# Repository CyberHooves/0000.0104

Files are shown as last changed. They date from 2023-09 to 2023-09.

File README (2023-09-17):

HAOS REDRO PN: 0000.0104
========================

This is a 1.2kW SMPS for audio amplifiers designed to fit within a 1U case.

Input: 400V DC
Output 1: +100V, 6A
Output 2: -100V, 6A
Output 3: +15V, 500mA
Output 4: -15V, 500mA
Output 5: +12V, 1A
Output 6: +12V, 500mA, referenced to Output 2.

The main outputs are unregulated and it is reccomended to use a suitable power factor correction circuit in applications where line regulation is necessary.
Auxiliary outputs 3 and 4 are provided for small-signal curcuits. Output 6 is provided for class-D amplifiers that require a gate drive supply referenced to the negative supply rail. 
Isolated and non-isolated inputs are provided to shut down the converter on J10 and J11, respectively. Oveheating protection is provided by a thermostat mounted on the heatsink.

This repository is released under CERN-OHL-S 2.0

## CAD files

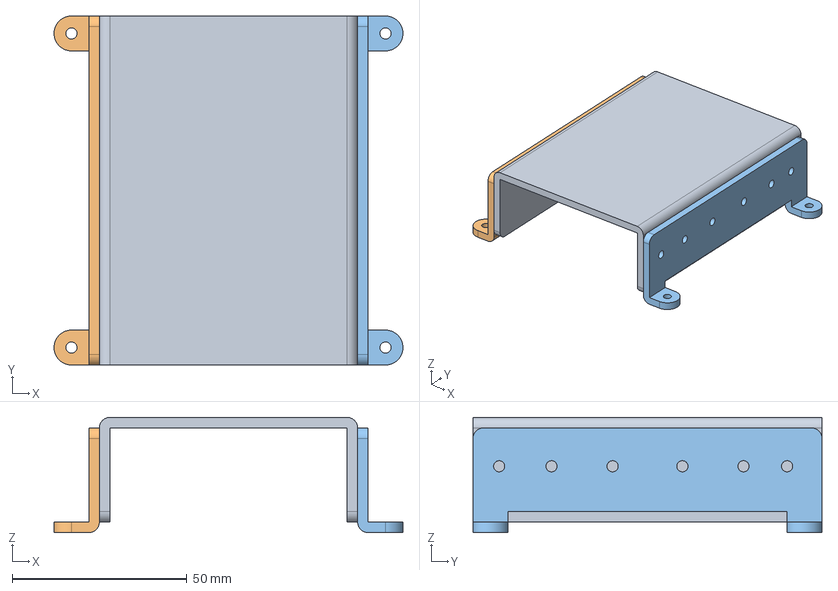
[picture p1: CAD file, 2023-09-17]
Heatsink.FCStd
100.0 x 100.0 x 33.0 mm
Top section
Primary side bracket
Secondary side bracket

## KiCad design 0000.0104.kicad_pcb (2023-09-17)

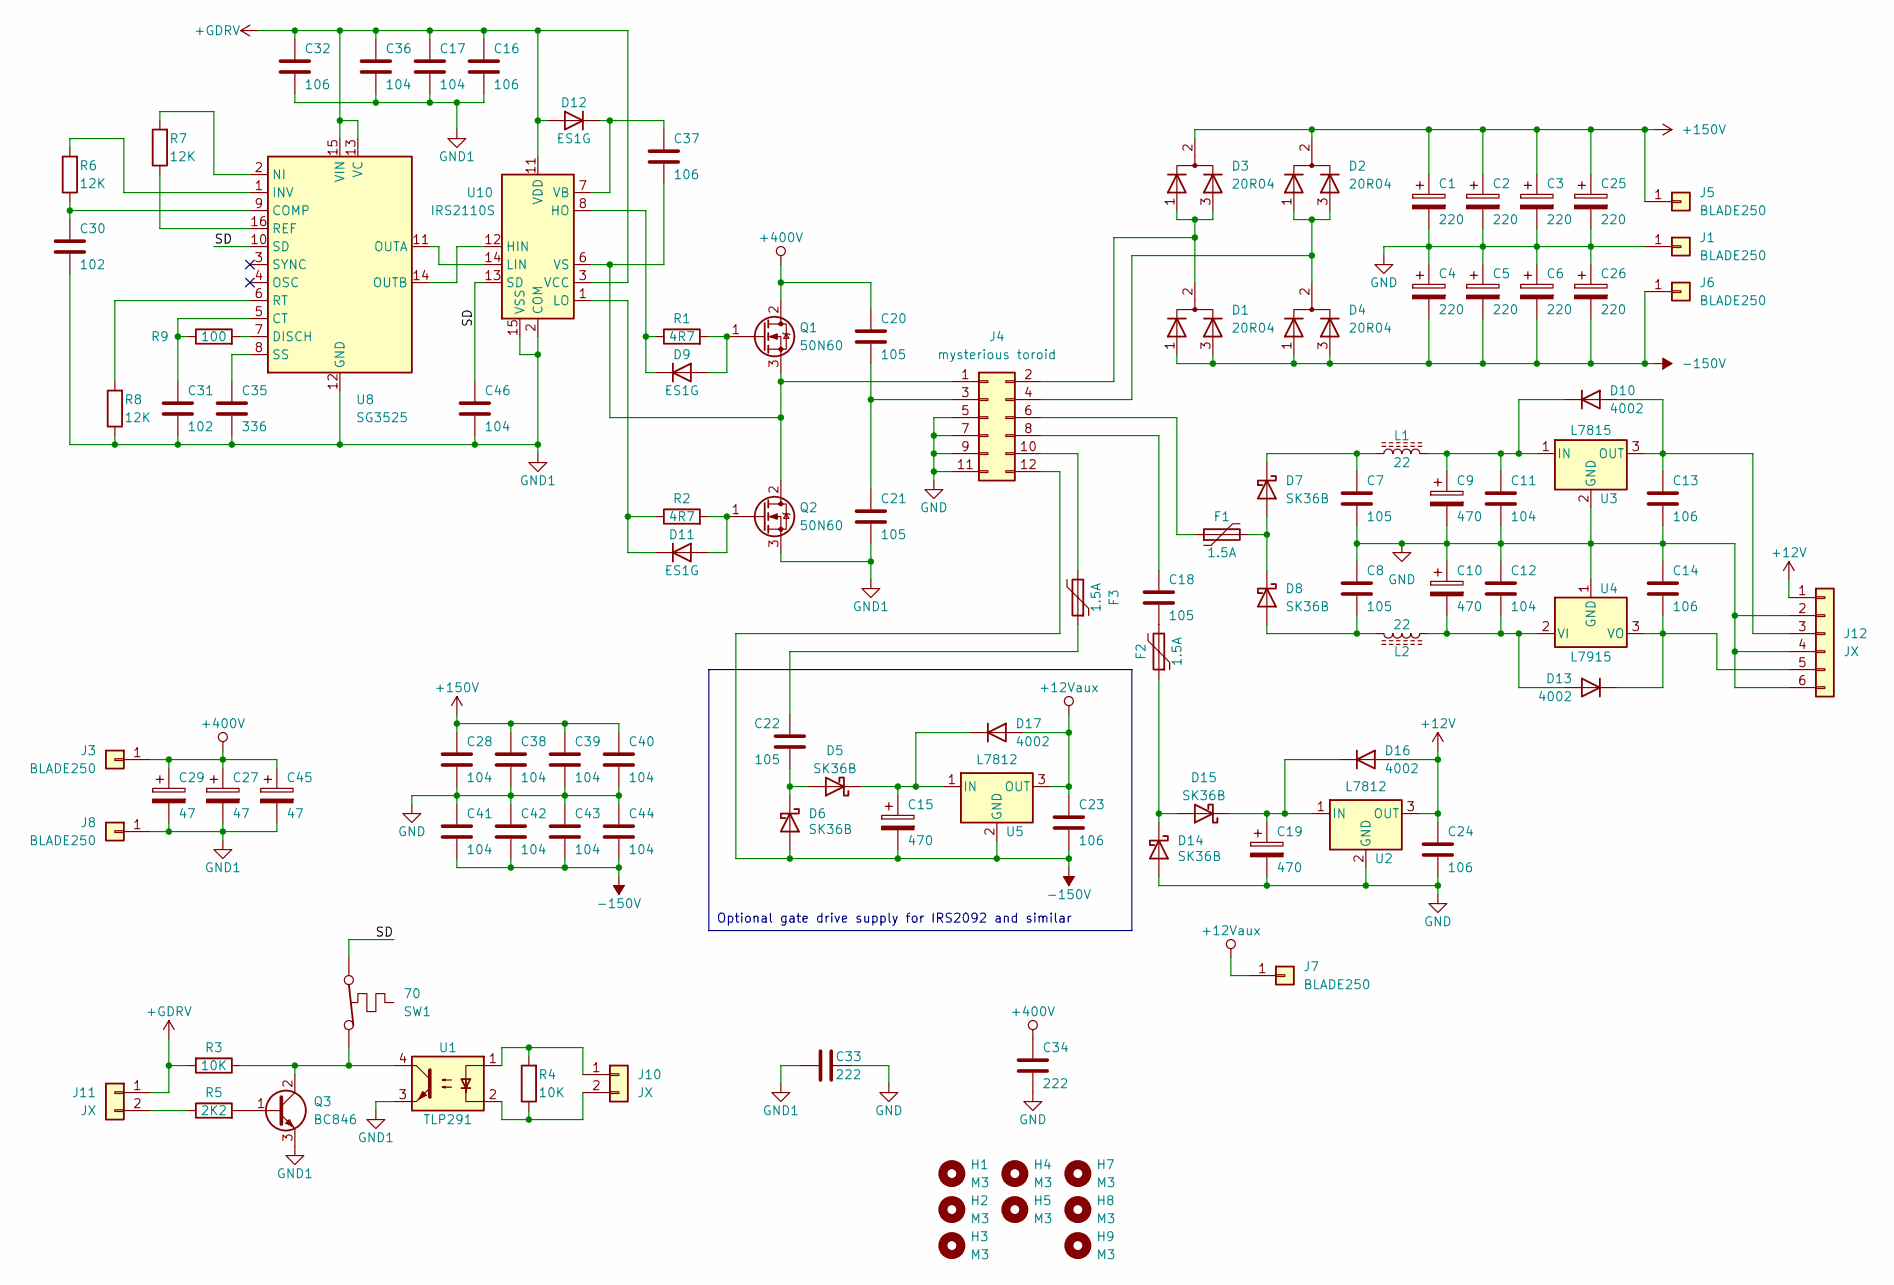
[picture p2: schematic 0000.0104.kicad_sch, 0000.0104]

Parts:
C1, C2, C3, C4, C5, C6, C25, C26: 220; CP_Radial_D16.0mm_P7.50mm
C7, C8, C18, C22: 105; C_1210_3225Metric
C9, C10, C15, C19: 470; CP_Radial_D10.0mm_P5.00mm
C11, C12, C17, C36, C46: 104; C_0805_2012Metric
C13, C14, C16, C23, C24, C32, C37: 106; C_1210_3225Metric
C20, C21: 105; C_Rect_L26.5mm_W11.5mm_P22.50mm_MKS4
C27, C29, C45: 47; CP_Radial_D18.0mm_P7.50mm
C28, C38, C39, C40, C41, C42, C43, C44: 104; C_1210_3225Metric
C30, C31: 102; C_0805_2012Metric
C33, C34: 222; C_Disc_D10.5mm_W5.0mm_P10.00mm
C35: 336; C_0805_2012Metric
D1, D2, D3, D4: 20R04; TO-220-3_Vertical_Staggered
D5, D6, D7, D8, D14, D15: SK36B; D_SMB
D9, D11, D12: ES1G; D_SMA
D10, D13, D16, D17: 4002; D_SMA
F1, F2, F3: 1.5A; Fuse_1210_3225Metric
H1, H2, H3, H4, H5, H7, H8, H9: M3; MountingHole_3.2mm_M3
J1, J3, J5, J6, J7, J8: BLADE250; CON-BLADE250-VERTICAL
J4: mysterious toroid; TRANSFORMER-TOROID-D55-H-8P-1
J10, J11: JX; JST_XA_B02B-XASK-1-A_1x02_P2.50mm_Vertical
J12: JX; JST_XA_B06B-XASK-1-A_1x06_P2.50mm_Vertical
L1, L2: 22; INDUCTOR_SMD_7x7
Q1, Q2: 50N60; TO-247-3_Vertical
Q3: BC846; SOT-23
R1, R2: 4R7; R_1210_3225Metric
R3, R4: 10K; R_0805_2012Metric
R5: 2K2; R_0805_2012Metric
R6, R7, R8: 12K; R_0805_2012Metric
R9: 100; R_0805_2012Metric
SW1: 70; TO-220-2_Vertical
U1: TLP291; DIP-4_W10.16mm
U2, U5: L7812; TO-220-3_Vertical
U3: L7815; TO-220-3_Vertical
U4: L7915; TO-220-3_Vertical
U8: SG3525; SO-16_3.9x9.9mm_P1.27mm
U10: IRS2110S; SOIC-16W_7.5x10.3mm_P1.27mm

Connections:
+12V: C24.1, D16.2 (A), J12.1, U2.3 (OUT)
+12Vaux: C23.1, D17.2 (A), J7.1, U5.3 (OUT)
+150V: C1.1, C2.1, C3.1, C25.1, C28.1, C38.1, C39.1, C40.1, D2.2 (A), D3.2 (A), J5.1
+400V: C20.1, C27.1, C29.1, C34.1, C45.1, J3.1, Q1.2 (D)
+GDRV: C16.1, C17.1, C32.1, C36.1, D12.2 (A), J11.1, R3.2, U8.13 (VC), U8.15 (VIN), U10.3 (VCC), U10.11 (VDD)
-150V: C4.2, C5.2, C6.2, C15.2, C23.2, C26.2, C41.2, C42.2, C43.2, C44.2, D1.1 (K), D1.3 (K), D4.1 (K), D4.3 (K), D6.2 (A), J4.12, J6.1, U5.2 (GND)
/SD: C46.1, SW1.1, U8.10 (SD), U10.13 (SD)
GND: C1.2, C2.2, C3.2, C4.1, C5.1, C6.1, C7.2, C8.1, C9.2, C10.1, C11.2, C12.1, C13.2, C14.1, C19.2, C24.2, C25.2, C26.1, C28.2, C33.2, C34.2, C38.2, C39.2, C40.2, C41.1, C42.1, C43.1, C44.1, D14.2 (A), J1.1, J4.5, J4.7, J4.9, J4.11, J12.2, J12.4, J12.6, U2.2 (GND), U3.2 (GND), U4.1 (GND)
GND1: C16.2, C17.2, C21.2, C27.2, C29.2, C30.2, C31.2, C32.2, C33.1, C35.2, C36.2, C45.2, C46.2, J8.1, Q2.3 (S), Q3.3 (E), R8.1, U1.3, U8.12 (GND), U10.2 (COM), U10.15 (VSS)
unnamed: C18.1, F2.2
unnamed: C22.2, F3.1
unnamed: D1.2 (A), D3.1 (K), D3.3 (K), J4.2
unnamed: D2.1 (K), D2.3 (K), D4.2 (A), J4.4
unnamed: C22.1, D5.2 (A), D6.1 (K)
unnamed: D7.2 (A), D8.1 (K), F1.2
unnamed: C7.1, D7.1 (K), L1.1
unnamed: C8.2, D8.2 (A), L2.1
unnamed: D9.2 (A), Q1.1 (G), R1.2
unnamed: D9.1 (K), R1.1, U10.8 (HO)
unnamed: C13.1, D10.2 (A), J12.3, U3.3 (OUT)
unnamed: C9.1, C11.1, D10.1 (K), L1.2, U3.1 (IN)
unnamed: D11.2 (A), Q2.1 (G), R2.2
unnamed: D11.1 (K), R2.1, U10.1 (LO)
unnamed: C37.1, D12.1 (K), U10.7 (VB)
unnamed: C10.2, C12.2, D13.2 (A), L2.2, U4.2 (VI)
unnamed: C14.2, D13.1 (K), J12.5, U4.3 (VO)
unnamed: D14.1 (K), D15.2 (A), F2.1
unnamed: C19.1, D15.1 (K), D16.1 (K), U2.1 (IN)
unnamed: C15.1, D5.1 (K), D17.1 (K), U5.1 (IN)
unnamed: C37.2, J4.1, Q1.3 (S), Q2.2 (D), U10.6 (VS)
unnamed: C20.2, C21.1, J4.3
unnamed: F1.1, J4.6
unnamed: C18.2, J4.8
unnamed: F3.2, J4.10
unnamed: J10.1, R4.2, U1.1
unnamed: J10.2, R4.1, U1.2
unnamed: J11.2, R5.1
unnamed: Q3.1 (B), R5.2
unnamed: Q3.2 (C), R3.1, SW1.2, U1.4
unnamed: C30.1, R6.1, U8.9 (COMP)
unnamed: C31.1, R9.1, U8.5 (CT)
unnamed: R9.2, U8.7 (DISCH)
unnamed: R6.2, U8.1 (INV)
unnamed: R7.2, U8.2 (NI)
unnamed: R7.1, U8.16 (REF)
unnamed: R8.2, U8.6 (RT)
unnamed: C35.1, U8.8 (SS)
unnamed: U8.14 (OUTB), U10.12 (HIN)
unnamed: U8.11 (OUTA), U10.14 (LIN)

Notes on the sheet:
Optional gate drive supply for IRS2092 and similar

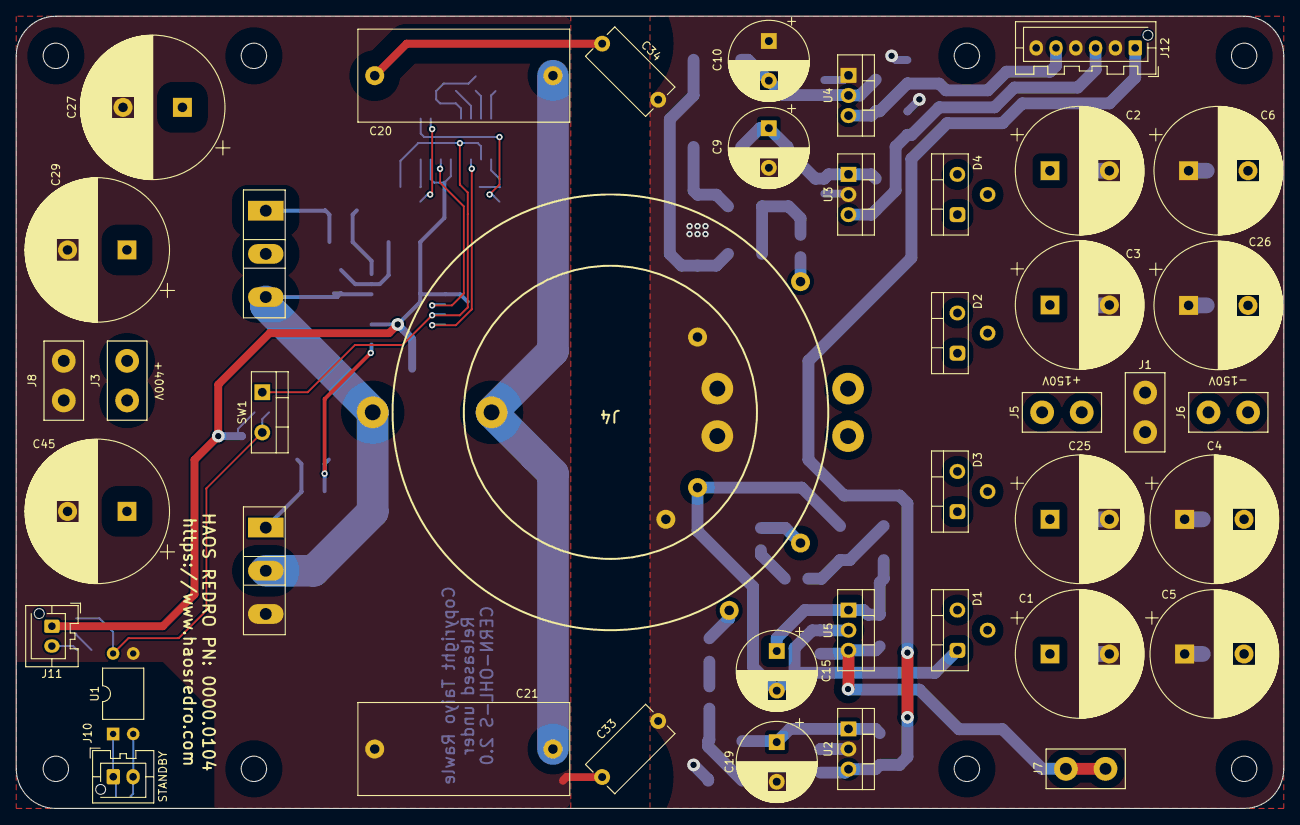
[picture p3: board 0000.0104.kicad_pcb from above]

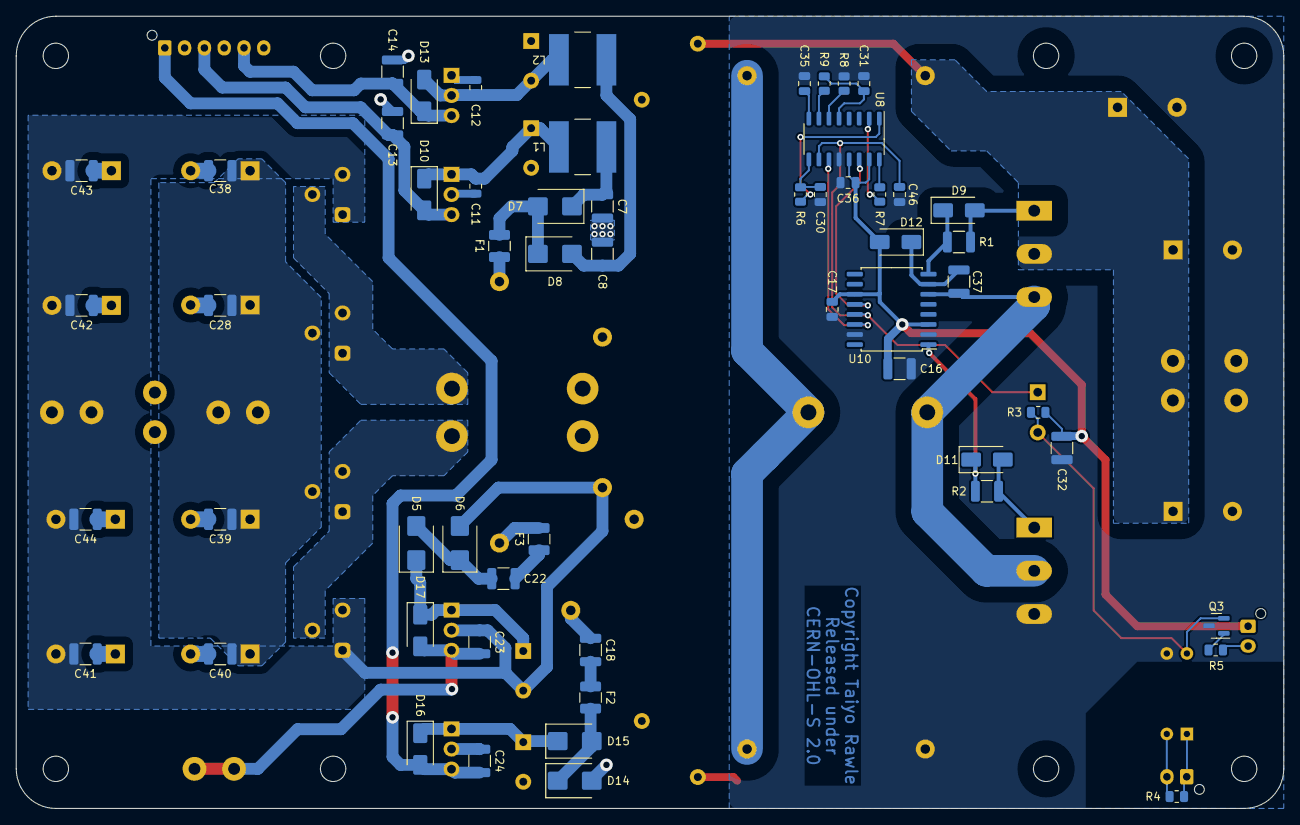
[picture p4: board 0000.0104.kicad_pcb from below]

Board: 2 copper layers, 160.0 x 100.0 mm, 106 parts (57 on the bottom side), 49 nets.

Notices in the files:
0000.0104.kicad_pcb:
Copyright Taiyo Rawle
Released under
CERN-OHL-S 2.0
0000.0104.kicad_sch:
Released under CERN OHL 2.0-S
